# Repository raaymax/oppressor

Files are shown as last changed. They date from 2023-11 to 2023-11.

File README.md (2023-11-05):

#  Oppressor - The Feline Discomfort Bot
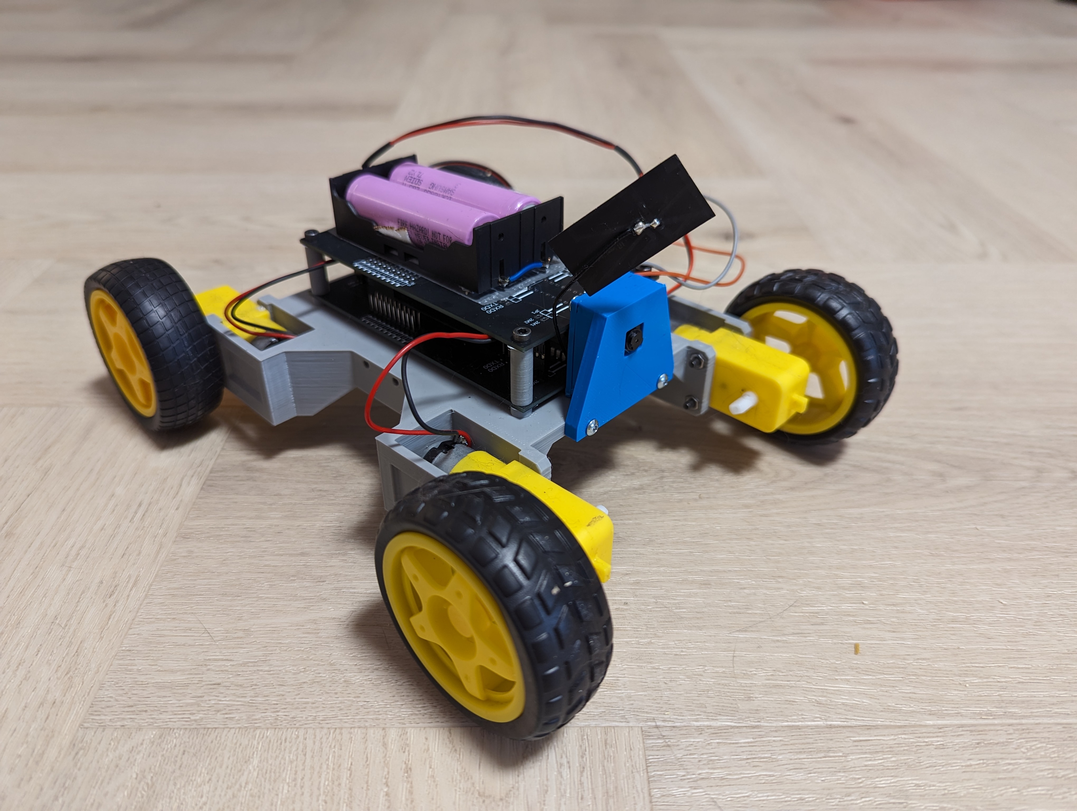
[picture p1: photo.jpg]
Oppressor photo


## Description

Welcome to the Oppressor project, where whimsy meets technology! Oppressor is not your typical robot; it doesn't conquer worlds or perform grand feats. Instead, it specializes in a unique and somewhat tongue-in-cheek mission – making cats feel a little uneasy.

## Project Details

Wireless Control: Oppressor is controlled using WiFi UDP packet transmission, allowing you to manipulate its behavior from the comfort of your laptop or any computer. This wireless control adds an element of surprise and delight to the interaction with your feline friends.

- **Custom PCB**: To bring Oppressor to life, we've designed a custom-made PCB (Printed Circuit Board) to ensure efficient and reliable operation. The PCB is at the heart of this project, facilitating seamless communication between the robot's components.

- **3D Printing Models**: We understand that the Oppressor community might want to explore customization. That's why we've included 3D printing models in the repository. These models can be used to create unique, personalized exteriors for your robot. Let your creativity run wild!

- **Video Stream**: Oppressor provides an immersive experience by offering a video stream feature powered by ESP32-CAM. This allows you to see the world from the robot's perspective, making for an even more engaging and entertaining experience.

- **Python Control Code**: The code for controlling Oppressor is written in Python, making it accessible and easy to modify for those who want to tweak the robot's behavior or add new features. This open-source nature encourages collaboration and innovation within the community.

## Purpose

The Oppressor project is all about adding a touch of whimsy to the world of robotics. It's a light-hearted experiment that explores how technology can interact with our four-legged friends. While Oppressor's name might sound intimidating, rest assured, it's all in good fun. Cats won't be harmed, only a little spooked.

## Parts list

- Seeed Xiao ESP32-S3 Sense 
- ESP32 devkitc?
- DC motors with wheels https://botland.com.pl/silniki-dc-katowe-z-przekladnia/3696-kolo-silnik-65x26mm-5v-z-przekladnia-48-1-5903351248129.html

## Build instructions

1. Order or make PCB based on schematics from `PCB/`
2. Print body on 3d printer `Models/Oppressor_body.stl`
3. Program esp32 with firmware from `Firmware/`
4. For esp32 cam https://github.com/rzeldent/esp32cam-rtsp is used
4. Solder all elements on your PCB
5. Assemble robot

## Video stream

[https://github.com/rzeldent/esp32cam-rtsp/tree/feature/seeed_xiao_esp32s3](https://github.com/rzeldent/esp32cam-rtsp/tree/feature/seeed_xiao_esp32s3)

## Usage

Turn on robot and check using USB serial whats it's IP address (baud: 115200). Connect to robot using `Control/` script and use arrows to control it. 
Have fun and go chasing some cats.

## Contributions

Feel free to contribute to Oppressor by adding new control features, enhancing the video stream, creating new 3D printing models, or optimizing the Python control code. This project is a canvas for creativity, where you can experiment with the boundaries of human-robot and feline-robot interactions.

Remember, Oppressor is a project with a sense of humor, aimed at celebrating the quirky relationship between technology and our feline companions. So, join us in creating an amusing and intriguing experience for cats and their humans!

## MIT License

Copyright (c) 2023 Mateusz Russak

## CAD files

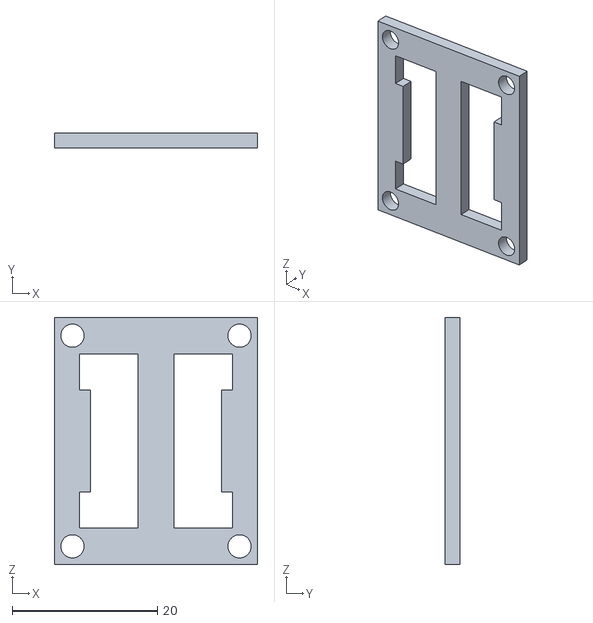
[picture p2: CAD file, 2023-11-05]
Models/Camera_mount_cover.stl
28.0 x 2.00 x 34.0

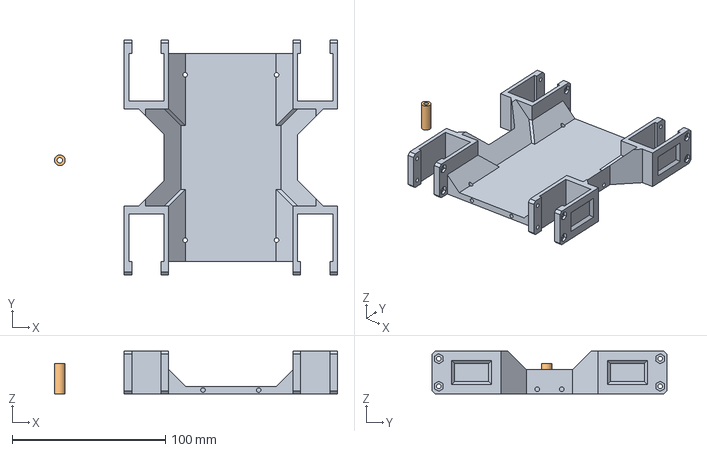
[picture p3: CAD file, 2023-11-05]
Models/Oppressor_body.step
184.8 x 153.6 x 28.0 mm

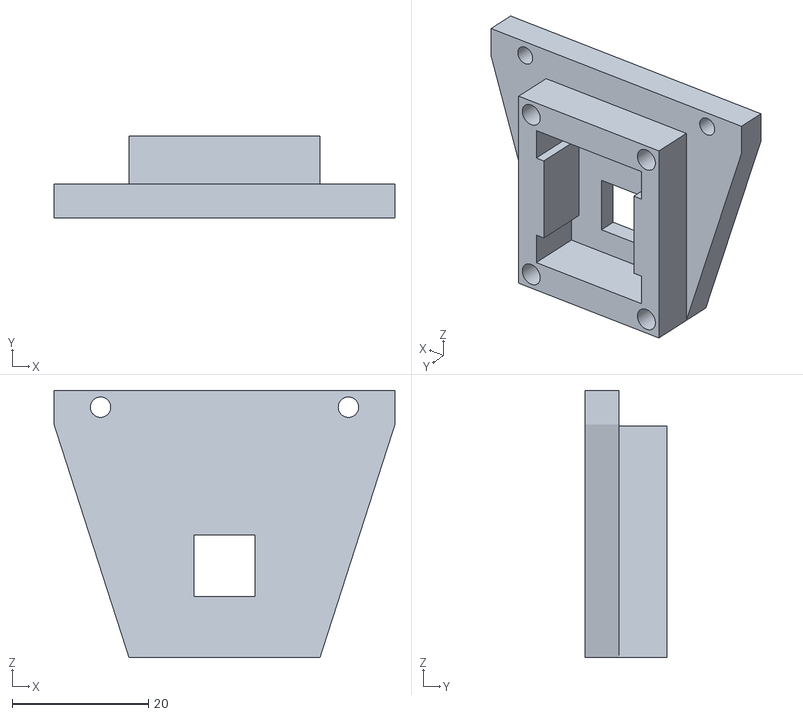
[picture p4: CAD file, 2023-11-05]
Models/Camera_mount.stl
50.0 x 12.0 x 39.2

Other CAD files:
Models/Oppressor_body.stl

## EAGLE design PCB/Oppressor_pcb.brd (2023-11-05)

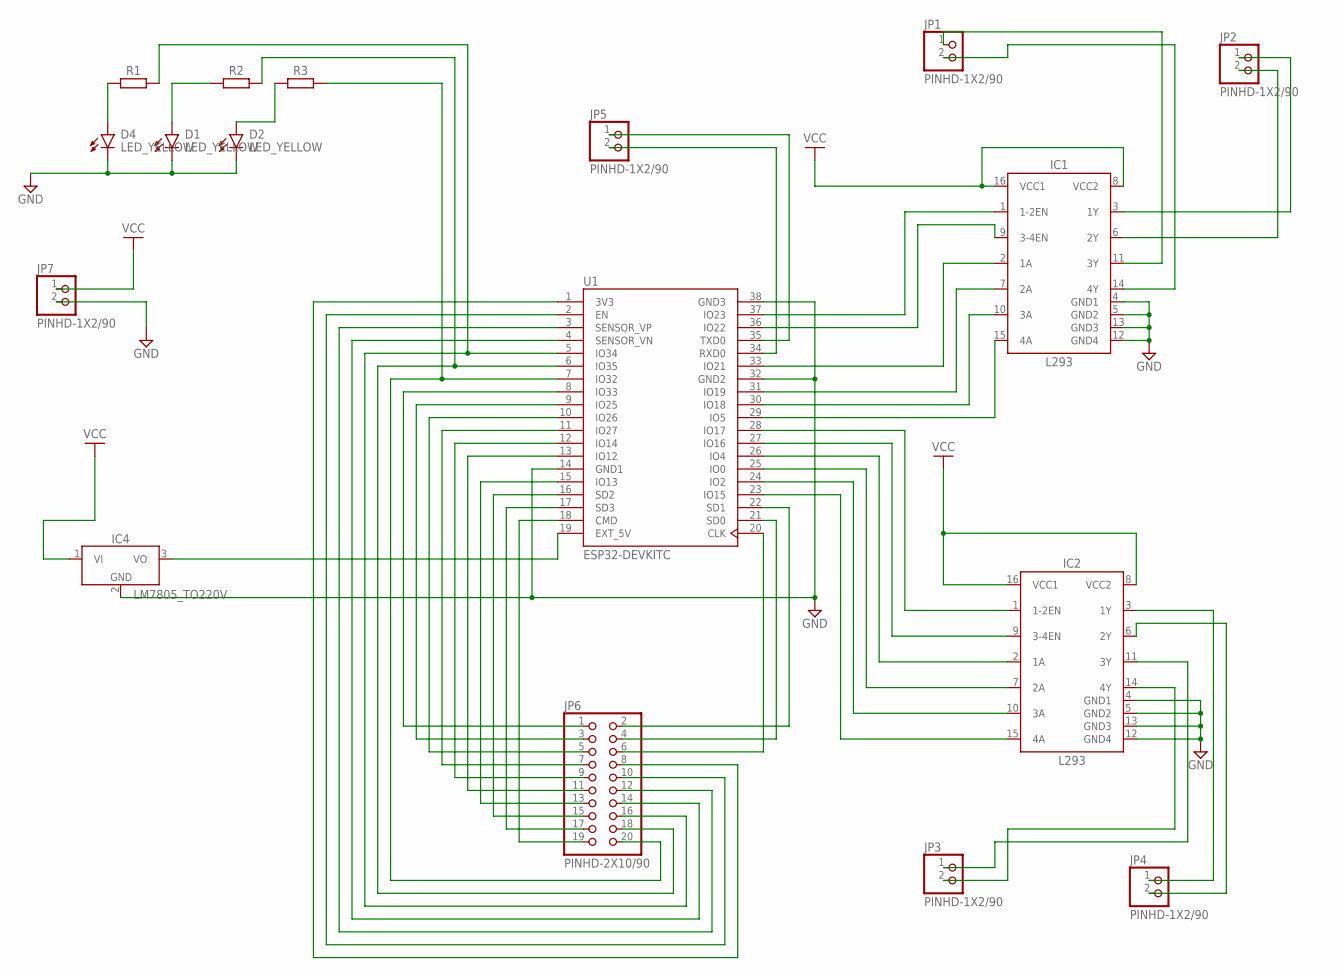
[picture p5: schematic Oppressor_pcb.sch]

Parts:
D1, D2, D4: LED_YELLOW; LEDC3224X250N_RND-Y
IC1, IC2: L293; DIP762W53P254L1969H508Q16B
IC4: LM7805_TO220V; TO220V
JP1, JP2, JP3, JP4, JP5, JP7: PINHD-1X2/90; 1X02/90
JP6: PINHD-2X10/90; 2X10/90
R1, R2, R3: R_AXIAL-7.2MM-PITCH; RESAD724W46L381D178B
U1: ESP32-DEVKITC; MODULE_ESP32-DEVKITC

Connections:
GND: D1.C, D2.C, D4.C, IC1.4 (GND1), IC1.5 (GND2), IC1.12 (GND4), IC1.13 (GND3), IC2.4 (GND1), IC2.5 (GND2), IC2.12 (GND4), IC2.13 (GND3), IC4.2 (GND), JP7.2, U1.14 (GND1), U1.32 (GND2), U1.38 (GND3)
unnamed: IC2.3 (1Y), JP4.1
unnamed: IC2.6 (2Y), JP4.2
unnamed: IC2.11 (3Y), JP3.1
unnamed: IC2.14 (4Y), JP3.2
unnamed: IC1.3 (1Y), JP2.1
unnamed: IC1.6 (2Y), JP2.2
unnamed: IC1.11 (3Y), JP1.1
unnamed: IC1.14 (4Y), JP1.2
unnamed: IC4.3 (VO), U1.19 (EXT_5V)
unnamed: IC1.1 (1-2EN), U1.37 (IO23)
unnamed: IC1.9 (3-4EN), U1.36 (IO22)
unnamed: IC1.2 (1A), U1.33 (IO21)
unnamed: IC1.7 (2A), U1.31 (IO19)
unnamed: IC1.10 (3A), U1.30 (IO18)
unnamed: IC1.15 (4A), U1.29 (IO5)
unnamed: IC2.1 (1-2EN), U1.28 (IO17)
unnamed: IC2.9 (3-4EN), U1.27 (IO16)
unnamed: IC2.2 (1A), U1.26 (IO4)
unnamed: IC2.7 (2A), U1.25 (IO0)
unnamed: IC2.10 (3A), U1.24 (IO2)
unnamed: IC2.15 (4A), U1.23 (IO15)
unnamed: JP5.1, U1.35 (TXD0)
unnamed: JP5.2, U1.34 (RXD0)
unnamed: JP6.2, U1.22 (SD1)
unnamed: JP6.4, U1.21 (SD0)
unnamed: JP6.6, U1.20 (CLK)
unnamed: JP6.17, U1.17 (SD3)
unnamed: JP6.19, U1.18 (CMD)
unnamed: JP6.15, U1.16 (SD2)
unnamed: JP6.13, U1.15 (IO13)
unnamed: JP6.11, U1.13 (IO12)
unnamed: JP6.9, U1.12 (IO14)
unnamed: JP6.7, U1.11 (IO27)
unnamed: JP6.5, U1.10 (IO26)
unnamed: JP6.3, U1.9 (IO25)
unnamed: JP6.1, U1.8 (IO33)
unnamed: JP6.14, U1.4 (SENSOR_VN)
unnamed: JP6.12, U1.3 (SENSOR_VP)
unnamed: JP6.10, U1.2 (EN)
unnamed: JP6.8, U1.1 (3V3)
unnamed: D4.A, R1.1
unnamed: D1.A, R2.1
unnamed: D2.A, R3.1
unnamed: JP6.16, R1.2, U1.5 (IO34)
unnamed: JP6.18, R2.2, U1.6 (IO35)
unnamed: JP6.20, R3.2, U1.7 (IO32)
VCC: IC1.8 (VCC2), IC1.16 (VCC1), IC2.8 (VCC2), IC2.16 (VCC1), IC4.1 (VI), JP7.1

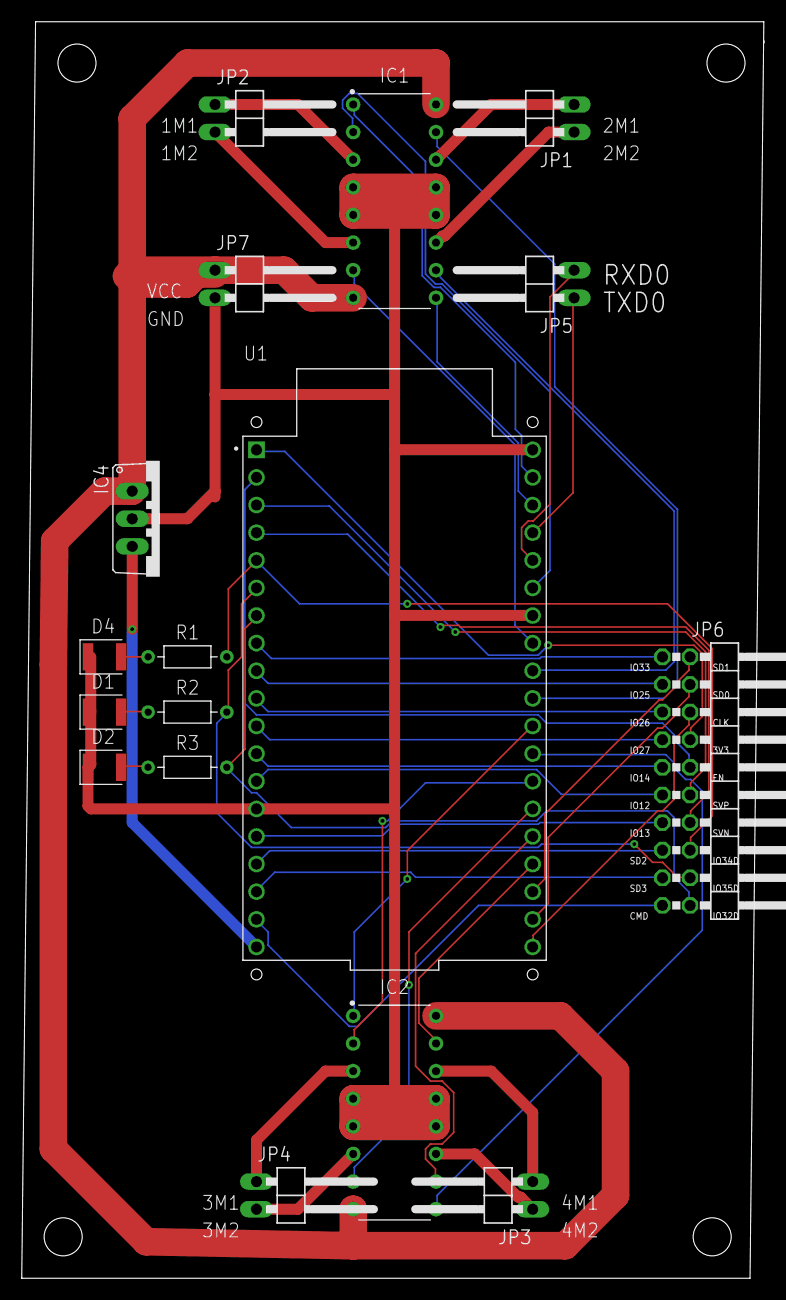
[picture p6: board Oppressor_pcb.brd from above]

Board: 2 copper layers, 68.2 x 115.6 mm, 17 parts (0 on the bottom side), 48 nets.

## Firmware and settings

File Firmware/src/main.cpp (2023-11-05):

#include <Arduino.h>
#include <WiFi.h>
#include "motors.h"
#include "server.h"
#include "status.h"

const char* ssid = "SSID";
const char* password = "PASSWORD";
HomeServer server;

void setup() {
  Motors.setup();
  Status.setup();
  WiFi.mode(WIFI_STA);
  WiFi.begin(ssid, password);
  Serial.print("Connecting to WiFi ..");
  while (WiFi.status() != WL_CONNECTED) {
    Serial.print('.');
    delay(1000);
  }
  Serial.begin(115200);
  while(!Serial){
    delay(100);
  }
  server.setup();
  Serial.println("Ready");
  Status.setOff();
  Status.setOnGreen();
  delay(1000);
  Status.setOffGreen();
  Status.setOnBlue();
  delay(1000);
  Status.setOffBlue();
  Status.setOnRed();
  delay(1000);
  Status.setOffRed();
}

void loop() {
  Status.loop();
  server.loop();
}

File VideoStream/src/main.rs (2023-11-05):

extern crate gstreamer as gst;
extern crate gstreamer_video as gst_video;
extern crate gtk;
extern crate glib;
extern crate reqwest;

use gst::prelude::*;

fn main() {
    // Initialize GStreamer
    gst::init().unwrap();
    let pipeline = gst::parse_launch("playbin uri=https://gstreamer.freedesktop.org/data/media/sintel_trailer-480p.webm").unwrap();
    pipeline.set_state(gst::State::Playing).unwrap();
    let bus = pipeline.bus().unwrap();
    let msg = bus.timed_pop_filtered(gst::ClockTime::NONE, gst::MessageType::Error).unwrap();
}

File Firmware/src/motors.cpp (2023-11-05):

#include "motors.h"

void MotorsClass::setup() {
  pinMode(MOTOR_FR_DIR_B_PIN, OUTPUT);
  pinMode(MOTOR_FR_DIR_F_PIN, OUTPUT);
  pinMode(MOTOR_FR_SPEED_PIN, OUTPUT);
  pinMode(MOTOR_FL_DIR_B_PIN, OUTPUT);
  pinMode(MOTOR_FL_DIR_F_PIN, OUTPUT);
  pinMode(MOTOR_FL_SPEED_PIN, OUTPUT);
  pinMode(MOTOR_BR_DIR_B_PIN, OUTPUT);
  pinMode(MOTOR_BR_DIR_F_PIN, OUTPUT);
  pinMode(MOTOR_BR_SPEED_PIN, OUTPUT);
  pinMode(MOTOR_BL_DIR_B_PIN, OUTPUT);
  pinMode(MOTOR_BL_DIR_F_PIN, OUTPUT);
  pinMode(MOTOR_BL_SPEED_PIN, OUTPUT);
  setSpeeds(0,0,0,0);
}

void MotorsClass::setSpeeds(int16_t fr, int16_t fl, int16_t br, int16_t bl){
  setMotorSpeed(MOTOR_FR, fr);
  setMotorSpeed(MOTOR_FL, fl);
  setMotorSpeed(MOTOR_BR, br);
  setMotorSpeed(MOTOR_BL, bl);
}

void MotorsClass::setMotorSpeed(uint8_t motor, int16_t speed){
  uint8_t dirF = speed > 0 ? 1 : 0;
  uint8_t dirB = speed < 0 ? 1 : 0;
  uint8_t s = abs(speed);
  switch(motor){
    case MOTOR_FR:
      digitalWrite(MOTOR_FR_DIR_F_PIN, dirF);
      digitalWrite(MOTOR_FR_DIR_B_PIN, dirB);
      analogWrite(MOTOR_FR_SPEED_PIN, s);
      break;
    case MOTOR_FL:
      digitalWrite(MOTOR_FL_DIR_F_PIN, dirF);
      digitalWrite(MOTOR_FL_DIR_B_PIN, dirB);
      analogWrite(MOTOR_FL_SPEED_PIN, s);
      break;
    case MOTOR_BR:
      digitalWrite(MOTOR_BR_DIR_F_PIN, dirF);
      digitalWrite(MOTOR_BR_DIR_B_PIN, dirB);
      analogWrite(MOTOR_BR_SPEED_PIN, s);
      break;
    case MOTOR_BL:
      digitalWrite(MOTOR_BL_DIR_F_PIN, dirF);
      digitalWrite(MOTOR_BL_DIR_B_PIN, dirB);
      analogWrite(MOTOR_BL_SPEED_PIN, s);
      break;
    default:
      break;
  }
}

MotorsClass Motors;

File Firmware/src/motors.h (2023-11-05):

#pragma once
#include <Arduino.h>

#define MOTOR_FR 0
#define MOTOR_FL 1
#define MOTOR_BR 2
#define MOTOR_BL 4

#define MOTOR_FR_DIR_F_PIN 21
#define MOTOR_FR_DIR_B_PIN 19

#define MOTOR_FL_DIR_F_PIN 18
#define MOTOR_FL_DIR_B_PIN 5

#define MOTOR_BR_DIR_F_PIN 4
#define MOTOR_BR_DIR_B_PIN 0

#define MOTOR_BL_DIR_F_PIN 2
#define MOTOR_BL_DIR_B_PIN 15

#define MOTOR_FR_SPEED_PIN 23
#define MOTOR_FL_SPEED_PIN 22
#define MOTOR_BR_SPEED_PIN 17
#define MOTOR_BL_SPEED_PIN 16

class MotorsClass {
public:   
    void setMotorSpeed(uint8_t motor, int16_t speed);
    void setSpeeds(int16_t fr, int16_t fl, int16_t br, int16_t bl);
    void setup();
};

extern MotorsClass Motors;
